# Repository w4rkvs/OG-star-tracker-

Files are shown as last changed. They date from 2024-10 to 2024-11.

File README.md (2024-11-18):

# OG-star-tracker-

Is a fully 3d printed upgradable star tracker that you can make for 60$, I have been working on it for the past two years. It can handle
up to 300mm and 2.5kg. It's also upgradable which means that you can add a another axis which would allow you to use go-to.Don't hesitate to ask me. 
- [List of parts](https://docs.google.com/spreadsheets/d/1kcgIab0JqNLg5WMselIyCQLZJsu3P-vXLvSJgl1yHa8)
- [Assembly video](https://www.youtube.com/watch?v=97YKJrmOWHY)

## Table of Contents
- [Old v1 of the Project](v1/README.md)
- [Mechanics](mechanics/README.md)
- [Firmware](esp32_wireless_control/README.md)

The kit can be purchased for around 150$ on [ogstartech.com](https://www.ogstartech.com/start/). There is a [discord](https://discord.gg/dyFKm79gKJ) for those who are interested or would want to ask me a few questions. New STLs are
on [printables](https://www.printables.com/model/348574-og-star-tracker).

## License

This work is licensed under a
[Creative Commons Attribution-NonCommercial-ShareAlike 4.0 International License](http://creativecommons.org/licenses/by-nc-sa/4.0/)



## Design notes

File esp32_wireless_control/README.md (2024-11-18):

# OG Star Tracker : Wireless Control Hardware (Rev 2.0)

This simple PCB and firmware intends to make it easier to control the OG Star Tracker. If you have any suggestions/ideas about new features or would like to contribute, post in the OG star tracker [discord server](https://discord.com/invite/dyFKm79gKJ) or message me (Discord: jahh#8924).
If you like this work, feel free to connect with me on [Github](https://github.com/jugal2001) or [Linkedin](https://www.linkedin.com/in/jugaljesing/).
### Features:
- Wirelessly Control the tracker from your phone/laptop by connecting to a webpage
- Supports AP (Access Point) and STA (Station) mode
 -- AP  : The ESP32 will create a wifi network which you can connect to
 -- STA : The ESP32 connects to an existing wifi network specified by you, Ex: phone hotspot. (Not fully tested)
- Integrated intervalometer which can control your camera shutter, no need to buy extra hardware. Exposures can be controlled via the webpage
- USB port to power a Dew Heater
- Slewing supported at different speeds.

*If you would like to buy an assembled PCB, contact Ondra Gejdos in the discord server (Creator of the OGST). Alternatively, if you live in India contact me to buy the PCB.*

## Table of Contents
- [PCB](pcb/README.md)
- [Compiling](docs/compiling.md)

## Building guide

One can get the full kit from the the official store at [ogstartech.com](https://ogstartech.com/start) or can build the tracker itself based on the instructions given at [printables](https://www.printables.com/model/348574-og-star-tracker)

## Firmware

The firmware for the PCB is provided in this repository and can be compiled and flashed with the given [instructions](docs/compiling.md).
To control the PCB the tracker will create its own wifi access point with the following default credentials:

```
ssid: OG Star Tracker
password: password123
```

After connection was successful the tracker to actually control it access the ***www.tracker.com** in your browser. The ESP32 provides a webserver for convenient controlling.

## App

If the webserver is not enough there is a app available to improve the accessibility even further.
Check out https://github.com/OndraGejdos/OG-star-tracker-App for more details.

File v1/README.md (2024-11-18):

## Wiring schematics

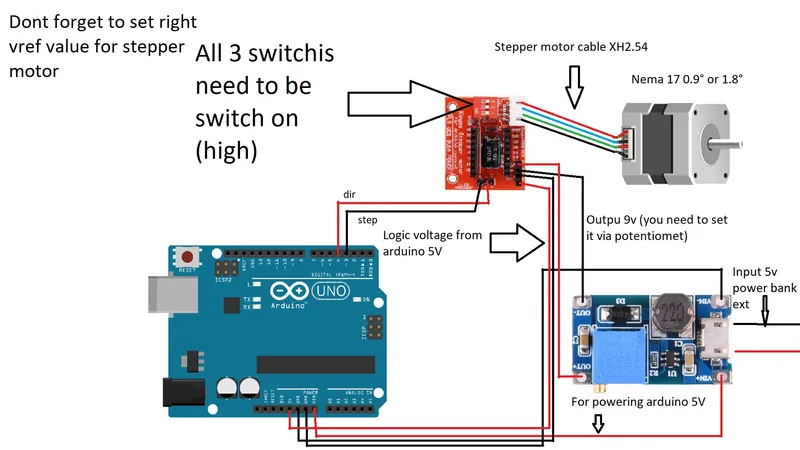
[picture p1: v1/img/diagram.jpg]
schematics


## Choosing parts
You need to main part that is adequate for your latitude. If you live betwen 0°-25° chose : **Main bottom part 0-25 use supports** , 25°-50° use : **Main bottom part 25-50**, 50°-65°+ up use : Main bottom part 45-65.  If you live between 60°-65° you need to use **Main part for laser (14mm) for north 60-65** and **Cover and tightener for north 60-65** because normal parts would not work so north or south.

## Firmware
You need to chose firmware based on your stepper motor. If you have stepper motor which has 400 steps per revolution chose :  firmware simple for Arduino nano 0.9° . If  you have 200 step per rotation stepper motor use : firmware simple for Arduino nano 1.8° . If you want to use different Arduino you might want to change out pins in code.

https://github.com/OndraGejdos/OG-star-tracker-/tree/main/v1/firmware

Or you can use our newly developed pcb to unlock more features. Also you dont need to wire it

https://github.com/OndraGejdos/OG-star-tracker-/tree/main/esp32_wireless_control

### Printing instructions :
Print all parts at 100% infill, except for the following where you can use lower infil:
  ·Large pulley: 50% infill
  ·Ball head holder: 50% infill
  ·Between part: 50% infill
  ·Stationary part: 50% infill
You can use a 0.6mm nozzle for faster printing
Use PLA as the printing material
Parts are oriented in the printing position
Use support only on these specific parts:
  ·Main part: overhang angle 60°
  ·Attachment for slider: overhang angle as specified by your slicer
If you think something is missing, please message me.
Soon, I will upload a bottom main part for those living below 20° latitude.
Clear skies!

3d printed parts chooser : https://docs.google.com/spreadsheets/d/16ynG4nyoBpZOIgJqL5DM0_ZiZSA8s_ifXBTfXa4CrJw/edit?usp=sharing

## Usage guide
You need to first turn it on.

Then you would point laser at polaris.

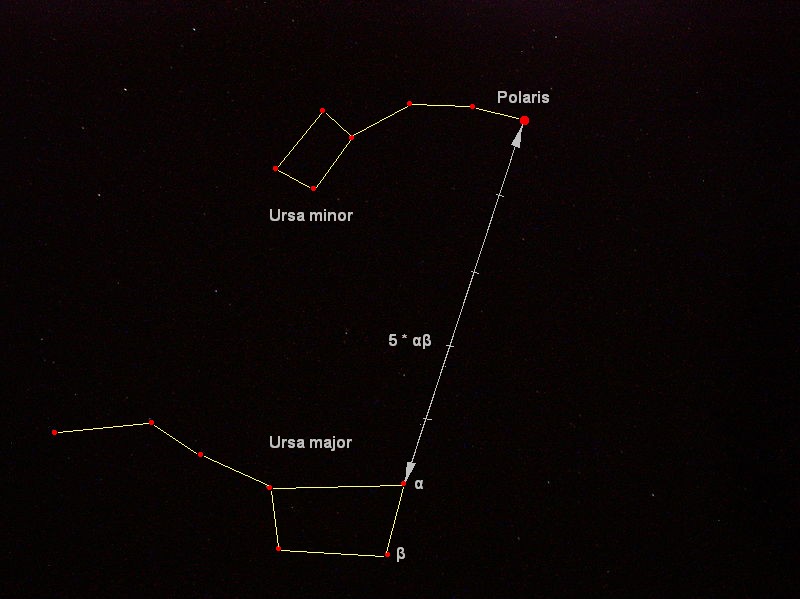
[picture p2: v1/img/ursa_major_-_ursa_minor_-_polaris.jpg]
usage

Then you can point at any celestial object and start shooting.

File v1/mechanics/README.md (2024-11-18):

# Printing Instructions

- OG star tracker mini: Print everything at 100% infill, except large pulley you can use 50% infill.
- For ball head holder, between part and stationary part you can use 50% infill
- For main part, use supports. Support overhang angle is 80°.
- STL files that have "2x" at the end, need to be printed twice.
- If you are confused, look at the 3D model.
- If you don't have M5 threaded inserts, use STLs that have "with thread" in the file name.
- For now, don't print top cover because the software is not ready yet.
- If you don't want to have intervalometer, print top cover without display.
- Software would be hopefully ready in few days.
- Don't forget that this is still beta.
- You can use 0.6mm nozzle.
- Use PLA for printing.
- Parts are oriented in printing position.
- Use supports only on this part: main part, overhang angle 80°
- Print M5 bolt cap twice
- If you think I have missed something, message me.
- Soon I will upload part bottom main part for peoples living below 20°.

Clear skies!

CC BY-NC-SA

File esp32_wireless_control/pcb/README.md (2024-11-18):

Below is list of all parts if you want to assemble it yourself.
### Part list:
| Symbol | Component | Quantity | Example |
|:-: |:-: |:-: |  ---- |
| C1 , C2 , C4  | 100uF 6.3mm Electrolytic Capacitor (THT)| 3 | https://www.sunrom.com/p/100uf-35v-63mm-samwha|
| D1 , D2 | 3mm Red LED THT | 2 | https://evelta.com/3-mm-red-led/ |
| J2 , J3 | 4-pin JST XH2.54mm Socket (90 degree) | 2 | https://www.sunrom.com/p/4-pin-jst-xh-25mm-side-entry-header  |
| J4 | 2.5mm Audio Jack | 1 | https://evelta.com/2-5mm-female-audio-jack-connector-3pin/|
| J5 | USB-A Receptacle | 1 | https://www.sunrom.com/p/usb-a-type-female-pcb-ra-short-body |
| R1 , R2 | 1.2K ohm THT Resistor | 2 | https://evelta.com/1-2k-ohm-resistance-pack-1-4-watt/|
| R3 |  68 ohm THT Resistor  | 1 | ^ |
| U1 | MT3608 Boost converter with USB |  1 |https://www.amazon.in/CENTIoT-MT3608-Adjustable-Module-Boost/dp/B07L6857QN|
| U2 | PC817 Optocoupler | 1 | https://www.sunrom.com/p/pc817-low-voltage-high-density-optocoupler|
| U3 | TMC2209 Stepper Driver| 1 | https://robu.in/product/tmc2209-v3-0-stepper-motor-driver-module/ |
| U5 | ESP32 Devkit V1 (30 pin)|  1 | https://www.electronicscomp.com/esp32-development-board-with-wifi-bluetooth-india|
| - | Female header pins | 2 strips (40x1) | https://www.sunrom.com/p/254mm-40x1-female-straight-header-strip|

### Note:
1. **J1** is a footprint for a 3.5mm audio socket, use this only if you cant find the correct 2.5mm part, or if your camera has a 3.5mm port. [Example](https://robu.in/product/smartelex-audio-jack-3-5mm-trrs-smd/)
2. **U6** is an optional footprint for a 6pin optocoupler in case you cant find a PC817. [MCT2E](https://projectpoint.in/datasheets/pdf/mct2e.pdf). Use only 1 of them.
3. **J5** USB-A Receptacle can be used to power a USB dew heater, dont solder this part if you dont plan to use a dew heater with this board.
4. **C3** is a ceramic cap connected to 3.3V-GND of the ESP32, no need to use this for now.

### Assembly:
- Here is what the fully assembled board is supposed to look like: (Use only 1 TMC2209 for now, only RA axis)

- Use female header pins to mount the TCM2209 drivers and the ESP32 so that they can be replaced easily
- The capacitors underneath the TMC2209 drivers need to be bent by 90-degree and rest on the PCB horizontally as shown:

- Keep the LED at sufficient height so that they can poke through the holes in top surface of the PCB enclosure

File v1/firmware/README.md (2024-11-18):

## Firmware

- step pin: A3
- dir pin: D4

If you want to use it in the south hemisphere, change dir from HIGH to LOW.

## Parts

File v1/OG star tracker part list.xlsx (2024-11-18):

 |  |  |  |  | Og star tracker
Thing you need to buy | price cca per 1ks | quantity | price $ | amazon or aliexpress for reference
625 bearing | 0.15 | 11 | 1.65 | https://www.aliexpress.com/item/32951064437.html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
16008 bearing | 4 | 2 | 8 | https://www.kugellager-express.de/deep-groove-ball-bearing-16008-open-oiled-40x68x9-mm
tmc2209 or 2208 | 7 | 1 | 7 | https://www.aliexpress.com/item/1005002625638207.html?curPageLogUid=98sOKqUEu4fy
gt2 48t pulley | 1 | 2 | 2 | https://www.aliexpress.com/item/1005002875709750.html?curPageLogUid=3kGxXn0tlHgc
gt2 16t pulley | 0.5 | 3 | 1.5 | https://www.aliexpress.com/item/32629617890.html?curPageLogUid=h4Z2GR4t9VFw
belt 122mm | 0.6 | 2 | 1.2 | https://www.aliexpress.com/item/1005004309993673.html?curPageLogUid=W4VxGfOuI1nQ
belt 400mm | 0.75 | 1 | 0.75 | https://www.aliexpress.com/item/1005003250288852.html?curPageLogUid=rBmudUUIxCXB
stepper motor 0,9° | 12 | 1 | 12 | https://www.aliexpress.com/item/1005003475800318.html?curPageLogUid=CAtzuvbHZAjn
you can use 1,8° but it is not so good |  |  | 0
motor driver board the red one | 1 | 1 | 1 | https://www.aliexpress.com/item/32908836265.html?scm_id=1007.13339.291025.0&scm-url=1007.13339.291025.0
arduino uno | 7.5 | 1 | 7.5 | https://www.aliexpress.com/item/32831857729.html?curPageLogUid=D2xkU3JT7git
gt2 idler pulley 20t without teeths bore 3 | 0.6 | 1 | 0.6 | https://www.aliexpress.com/item/32971394035.html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
m5x25 socket head |  | 1 |  |  | buy in your local hardvare store
m5x16 socket head |  | 1 |  |  | buy in your local hardvare store
m3x20 socket head |  | 5 |  |  | buy in your local hardvare store
m5x50 hex head |  | 2 |  |  | buy in your local hardvare store
m3x8 socket head |  | 18 |  |  | buy in your local hardvare store
m3x16 socket head |  | 2 |  |  | buy in your local hardvare store
m3x16 hex head |  | 1 |  |  | buy in your local hardvare store
m3x12 socket head |  | 5 |  |  | buy in your local hardvare store
m3x16 hex head |  | 2 |  |  | buy in your local hardvare store
m5 nut |  | 3 |  |  | buy in your local hardvare store
m3 thread rod 90mm |  | 1 |  |  | buy in your local hardvare store
5mm rod 50mm |  | 2 |  |  | buy in your local hardvare store
m3x6 |  | 18 |  |  | buy in your local hardvare store
m3 threaded inserts |  | 55 | 10 | price for screws and inserts and rods | buy in your local hardvare store
filament pla cca 0,5kg |  | 1 | 10
lcd display with keyes | 2.5 | 1 | 2.5 | https://www.aliexpress.com/item/32842943705.html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
step up |  | 1 | 0.5 | https://www.aliexpress.com/item/1005003112775752.html?curPageLogUid=uhuP8A2T9S2b
cabel for stepper motor (if you dont have) | 0.7 | 1 |  | https://www.aliexpress.com/item/32811275446.html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
 |  | entire price : | 66.2
 |  | price wtihout pla | 55.7 | You make it cheaper if you would buy 1,8° stepper motor no lcd and tmc 2209 in pack of 5 instead of 1 and if you would buy arduino nano. And if you would bought some things second hand . You might be able to do it for ~45 $ if you would try a lot.
optional
threaded insert m5 |  | 3
threaded inseter m3 short |  | 1
parts needed for usage that are not part of assemby
laser pointer get more powerful thean 5mw |  |  | 17 |  |  | lasers are dangerous they can couse serious harm | https://www.amazon.com/Wireless-Demonstrator-Construction-Demonstration-Instruction/dp/B0B94DVX3D
ball head get some that can handle at least 3kg |  |  | 17 |  |  | https://www.aliexpress.com/item/4001227791651.html?curPageLogUid=aTqITsL0oPSzz
good tripod |  |  | ~30 |  |  | buy or get second hand . second hand you might buy surveyors tripods
 |  | with addons | 89.7
Things that you need to own
3d printer
soldering iron (you can do it without)

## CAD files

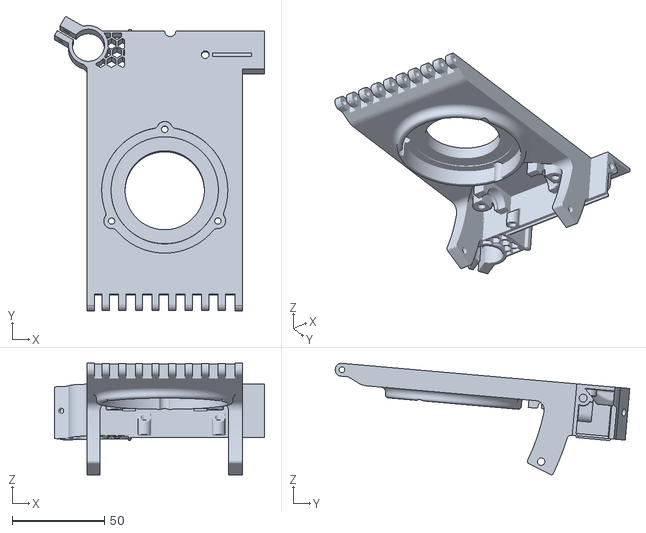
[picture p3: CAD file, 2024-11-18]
mechanics/Main part for different sizes of polar scopes and lasers/Main part for laser or polarscope 17.5mm.stl
113.9 x 159.8 x 60.5

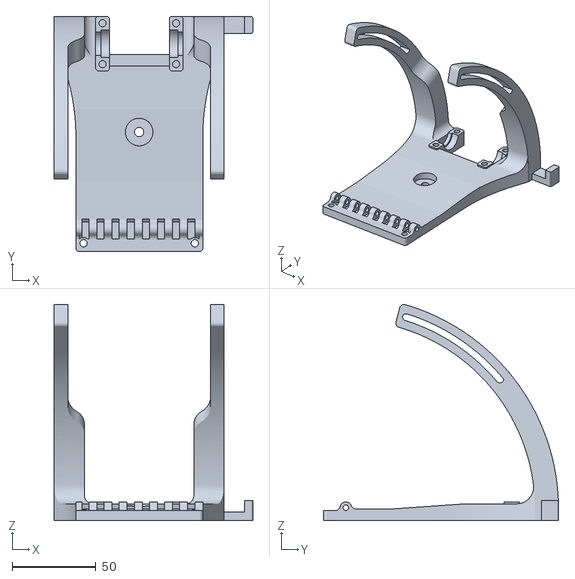
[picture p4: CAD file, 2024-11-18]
mechanics/Bottom assembly/Main bottom part 0-25.stl
118.2 x 139.9 x 128.7

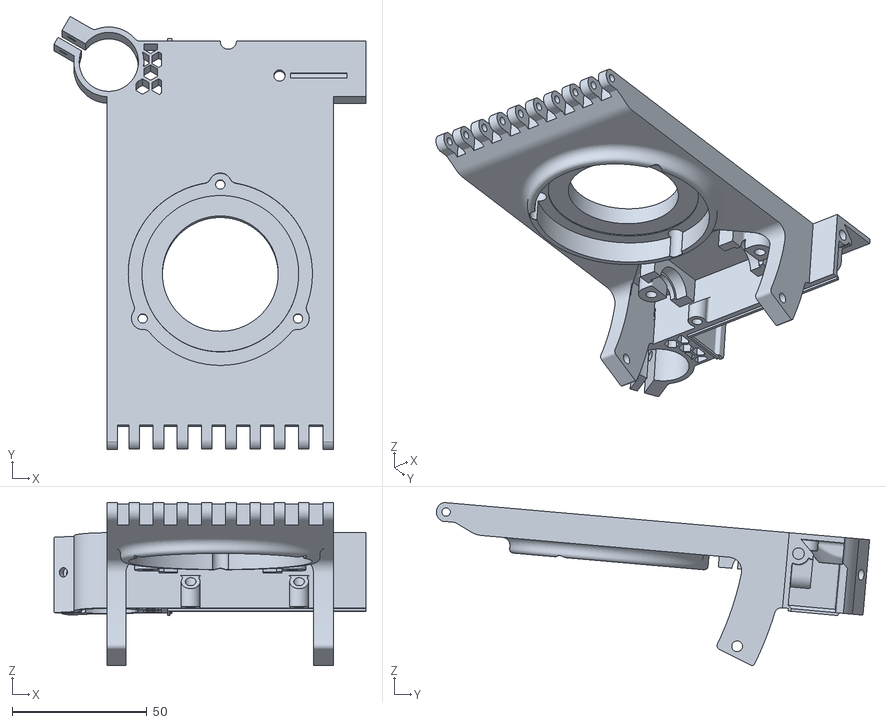
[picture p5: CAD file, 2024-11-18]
mechanics/Main part for different sizes of polar scopes and lasers/Main part for laser or polarscope 22mm.stl
115.9 x 160.9 x 60.5

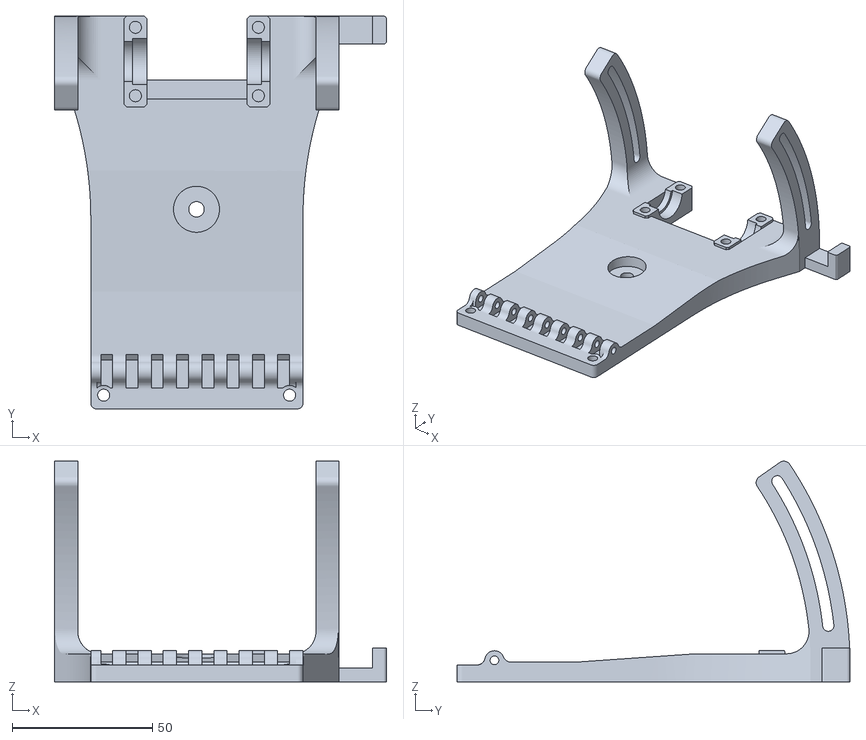
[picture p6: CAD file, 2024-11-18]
mechanics/Bottom assembly/Main bottom part 45 - 65.stl
118.2 x 139.9 x 78.6

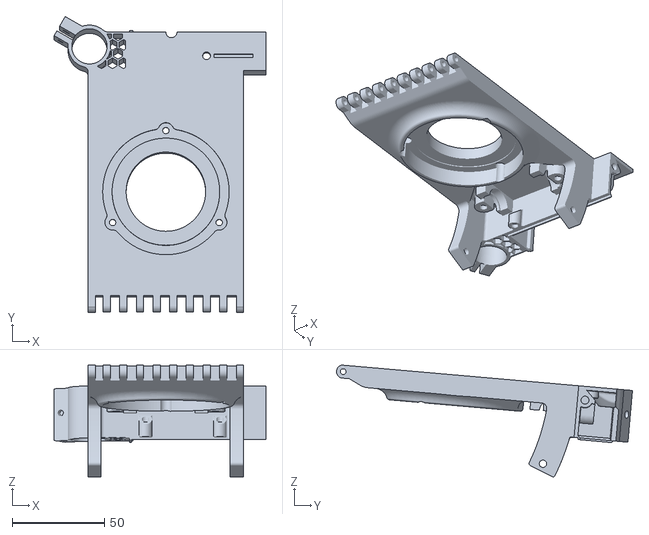
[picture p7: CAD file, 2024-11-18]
mechanics/Main part for different sizes of polar scopes and lasers/Main part for polar scope 19mm.stl
114.6 x 160.2 x 60.5

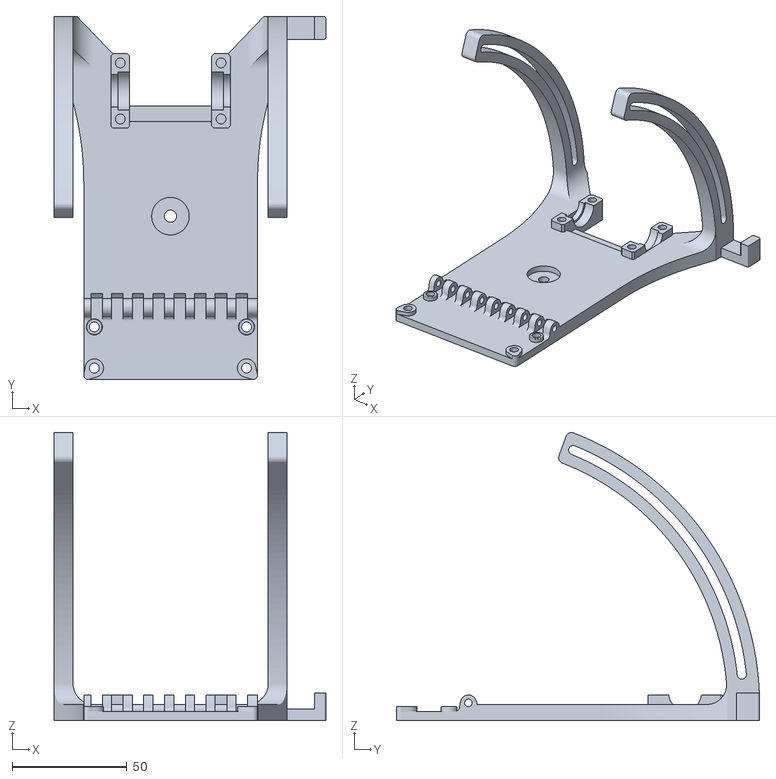
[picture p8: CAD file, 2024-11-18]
v1/mechanics/bottom asembly/bottom main part.stl
118.2 x 157.9 x 125.2

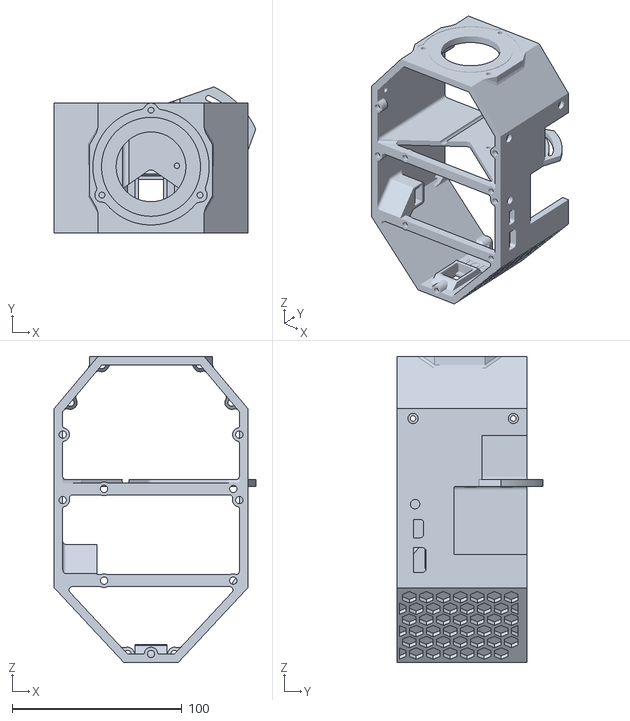
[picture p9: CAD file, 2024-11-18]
mechanics/DEC upgrade RADEK/main-part.stl
118.6 x 86.0 x 180.0

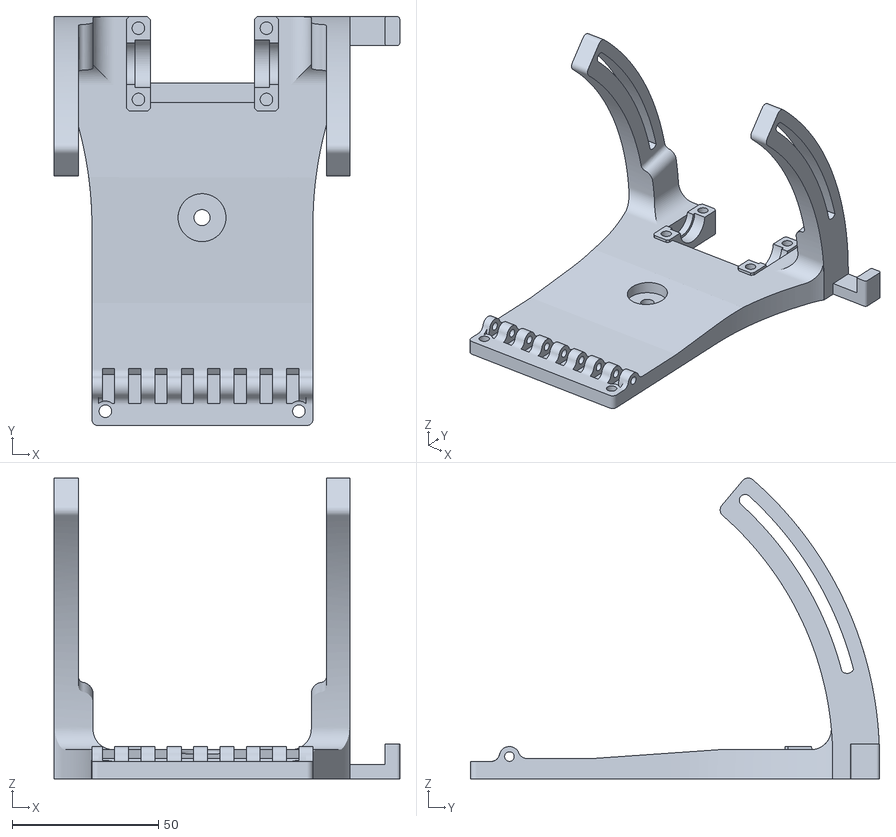
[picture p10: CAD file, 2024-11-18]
mechanics/Bottom assembly/Main bottom part 25-50.stl
118.2 x 139.9 x 102.9

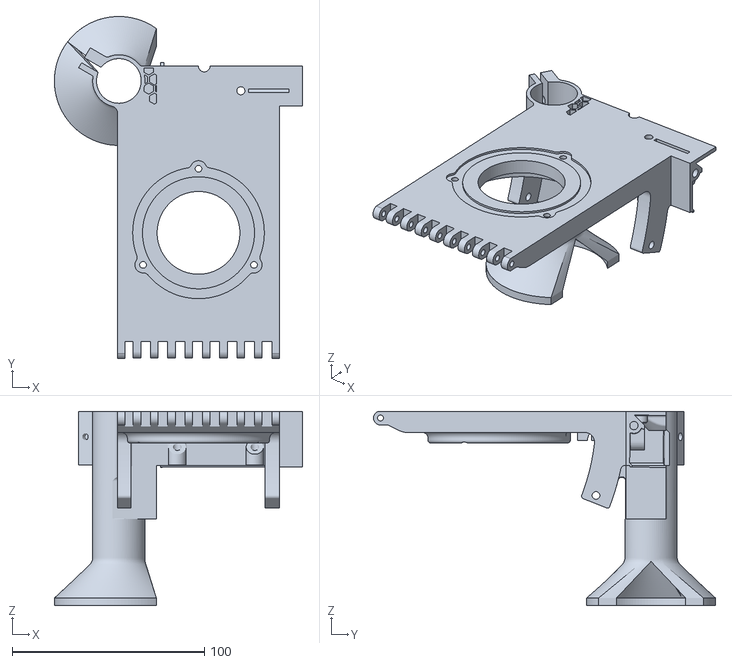
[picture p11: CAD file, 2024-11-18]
mechanics/Main part for different sizes of polar scopes and lasers/Main part for eq3-2 polar scope.stl
129.0 x 177.7 x 101.0

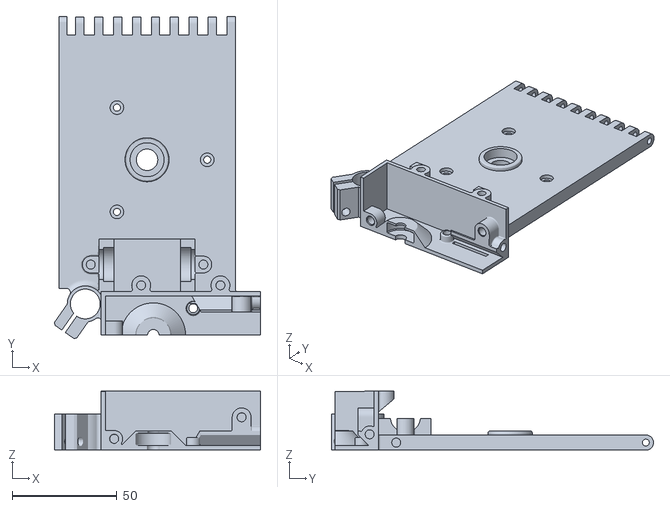
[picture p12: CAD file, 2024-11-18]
v1/mechanics/top asembly/main part.stl
98.2 x 153.5 x 28.0

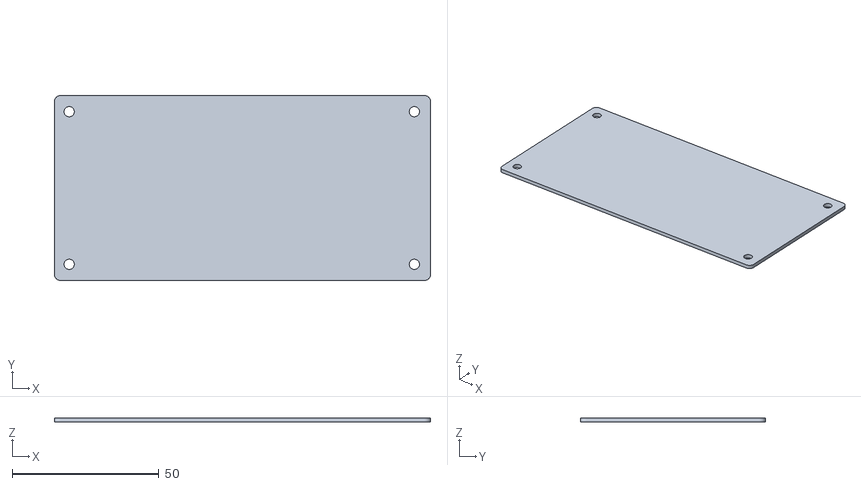
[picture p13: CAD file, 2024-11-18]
mechanics/arduino box/top cover without display.stl
128.1 x 63.0 x 1.50

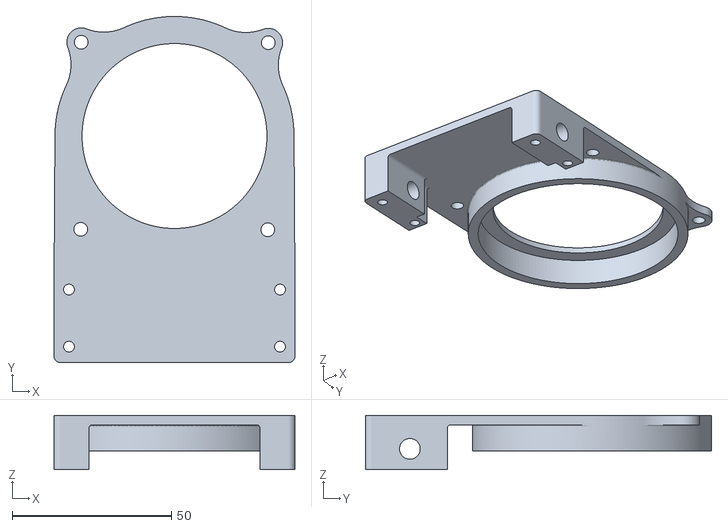
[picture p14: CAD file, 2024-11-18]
mechanics/Bottom assembly/Middle holder of bearing with m5 threaded insert.stl
75.6 x 108.6 x 17.1

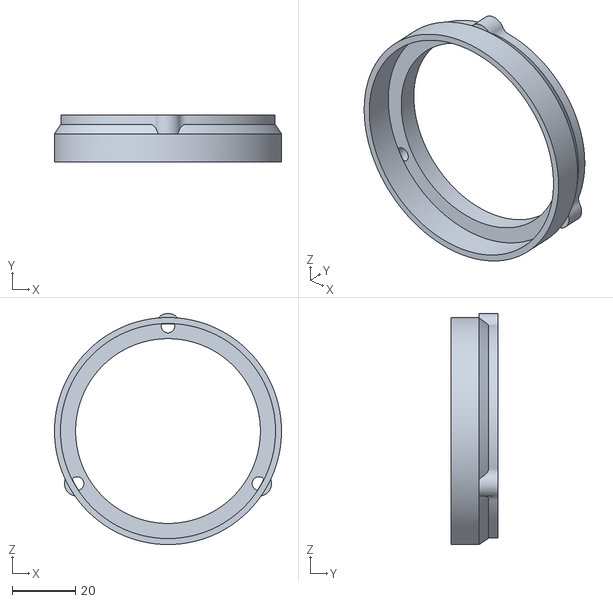
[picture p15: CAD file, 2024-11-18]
mechanics/DEC upgrade RADEK/middle-bearing-holder.stl
72.0 x 15.0 x 73.3

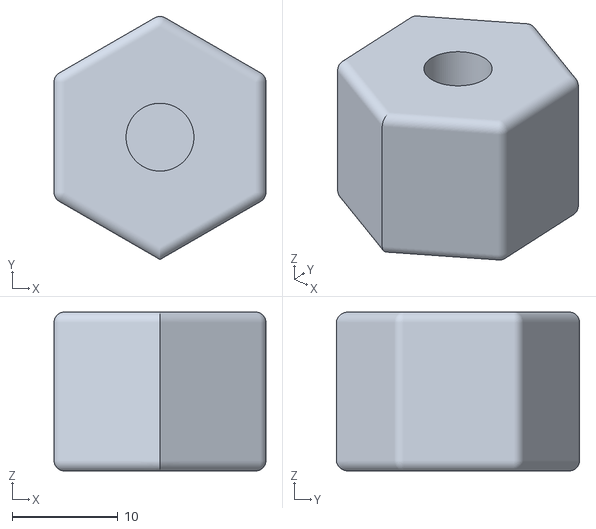
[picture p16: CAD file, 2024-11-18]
mechanics/Knobs and rest of the things/rotator with m5 threaded insert.stl
20.0 x 22.9 x 15.0

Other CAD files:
mechanics/Main part for different sizes of polar scopes and lasers/Main part for laser 14mm.stl
mechanics/Main part for different sizes of polar scopes and lasers/Main part for laser or polarscope 23mm.stl
mechanics/Main part for different sizes of polar scopes and lasers/Main part for laser (14mm) for north 60-65.stl
mechanics/Pcb box/Bottom part of the box.stl
mechanics/Bottom assembly/Stationary part all threads are 3d printed.stl
mechanics/Bottom assembly/Stationary part for surveyors tripod with m5 threaded insert.stl
mechanics/Bottom assembly/Stationary part with m5 threaded inser and 3 8 threaded insert.stl
mechanics/Bottom assembly/Stationary part with m5 threaded inser and 3d printed 1 4 thread.stl
mechanics/Bottom assembly/stationary-part-3-8-thread-m5-insert.stl
mechanics/DEC upgrade RADEK/DEC_Arca_clamp_moving.stl
mechanics/DEC upgrade RADEK/DEC_Arca_clamp_static.stl
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

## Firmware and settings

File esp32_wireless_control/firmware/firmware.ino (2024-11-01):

#include <WiFi.h>
#include <WebServer.h>
#include <DNSServer.h>
#include <string.h>
#include <esp_wifi.h>
#include <EEPROM.h>
#include "config.h"
#include "strings.h"

// try to update every time there is breaking change
const int firmware_version = 6;

// Set your Wi-Fi credentials
const byte DNS_PORT = 53;
const char* ssid = "OG Star Tracker";  //change to your SSID
const char* password = "password123";  //change to your password, must be 8+ characters
//If you are using AP mode, you can access the website using the below URL
const String website_name = "www.tracker.com";
const int dither_intensity = 5;
#define MIN_CUSTOM_SLEW_RATE 2

//Time b/w two rising edges should be 133.3333 ms
//66.666x2  ms
//sidereal rate = 0.00416 deg/s
//for 80Mhz APB (TIMER frequency)
#ifdef STEPPER_0_9
enum tracking_rate_state { TRACKING_SIDEREAL = 2659383,  //SIDEREAL (23h,56 min)
                           TRACKING_SOLAR = 2666666,     //SOLAR (24h)
                           TRACKING_LUNAR = 2723867 };   //LUNAR (24h, 31 min)
const int arcsec_per_step = 2;
#else  //stepper 1.8 deg
enum tracking_rate_state { TRACKING_SIDEREAL = 5318765,  //SIDEREAL (23h,56 min)
                           TRACKING_SOLAR = 5333333,     //SOLAR (24h)
                           TRACKING_LUNAR = 5447735 };   //LUNAR (24h, 31 min)
const int arcsec_per_step = 4;
#endif

volatile enum tracking_rate_state tracking_rate = TRACKING_SIDEREAL;  //default to sidereal rate

int slew_speed = 0, exposure_count = 0, exposure_duration = 0, dither_enabled = 0, focal_length = 0, pixel_size = 0, steps_per_10pixels = 0, direction = c_DIRECTION;
float arcsec_per_pixel = 0.0;
unsigned long blink_millis = 0;
uint64_t exposure_delay = 0;

//state variables
bool s_slew_active = false, s_tracking_active = true, s_capturing = false;  //change s_tracking_active state to false if you want tracker to be OFF on power-up
bool disable_tracking = false;
int exposures_taken = 0;
enum photo_control_state { ACTIVE,
                           DELAY,
                           DITHER,
                           INACTIVE };
volatile enum photo_control_state photo_control_status = INACTIVE;

float direction_left_bias = 0.5, direction_right_bias = 0.5;
int previous_direction = -1;

//2 bytes occupied by each int
//eeprom addresses
#define DITHER_ADDR 1
#define FOCAL_LEN_ADDR 3
#define PIXEL_SIZE_ADDR 5
#define DITHER_PIXELS 30  //how many pixels to dither

WebServer server(80);
DNSServer dnsServer;
hw_timer_t* timer_tracking = NULL;     //for tracking and slewing rate
hw_timer_t* timer_interval = NULL;     //for intervalometer control
hw_timer_t* timer_web_timeout = NULL;  //for webclient timeout control

void IRAM_ATTR timer_web_timeout_ISR() {
  handleSlewOff();
}

void IRAM_ATTR timer_tracking_ISR() {
  //tracking ISR
  digitalWrite(AXIS1_STEP, !digitalRead(AXIS1_STEP));  //toggle step pin at required frequency
}

void IRAM_ATTR timer_interval_ISR() {
  Serial.println("----");
  //intervalometer ISR
  switch (photo_control_status) {
    case ACTIVE:
      exposures_taken++;
      Serial.println("exposures_taken = " + String(exposures_taken) + "/" + String(exposure_count));
      if (exposure_count == exposures_taken) {
        Serial.println("State: Stopping intervalometer");
        // no more images to capture, stop
        disableIntervalometer();
        exposure_count = 0;
        s_capturing = false;
        photo_control_status = INACTIVE;

        if (disable_tracking) {
          s_tracking_active = false;
          timerAlarmDisable(timer_tracking);
        }
      } else if (exposures_taken % 3 == 0 && dither_enabled) {
        Serial.println("State: Dithering");
        // user has active dithering and this is %3 image, stop capturing and run dither routine
        photo_control_status = DITHER;
        stopCapture();
        timerStop(timer_interval);  //pause the timer, wait for dither to finish in main loop
      } else {
        Serial.println("State: Wait for next shot");
        // run normally
        timerWrite(timer_interval, exposure_delay);
        stopCapture();
        photo_control_status = DELAY;
      }
      break;
    case DELAY:
      Serial.println("State: Taking shot");
      timerWrite(timer_interval, 0);
      startCapture();
      photo_control_status = ACTIVE;
      break;
  }
}

// Handle requests to the root URL ("/")
void handleRoot() {
  String formattedHtmlPage = String(html);
  formattedHtmlPage.replace("%north%", (direction ? "selected" : ""));
  formattedHtmlPage.replace("%south%", (!direction ? "selected" : ""));
  formattedHtmlPage.replace("%dither%", (dither_enabled ? "checked" : ""));
  formattedHtmlPage.replace("%focallen%", String(focal_length).c_str());
  formattedHtmlPage.replace("%pixsize%", String((float)pixel_size / 100, 2).c_str());
  server.send(200, MIME_TYPE_HTML, formattedHtmlPage);
}

void handleOn() {
  int tracking_speed = server.arg(TRACKING_SPEED).toInt();
  switch (tracking_speed) {
    case 0:  //sidereal rate
      tracking_rate = TRACKING_SIDEREAL;
      break;
    case 1:  //solar rate
      tracking_rate = TRACKING_SOLAR;
      break;
    case 2:  //lunar rate
      tracking_rate = TRACKING_LUNAR;
      break;
    default:
      tracking_rate = TRACKING_SIDEREAL;
      break;
  }
  direction = server.arg(DIRECTION).toInt();
  s_tracking_active = true;
  initTracking();
}

void handleOff() {
  s_tracking_active = false;
  timerAlarmDisable(timer_tracking);
  server.send(200, MIME_TYPE_TEXT, TRACKING_OFF);
}

void handleLeft() {
  if (!s_slew_active) {  //if slew is not active - needed for ipad (passes multiple touchon events)
    slew_speed = server.arg(SPEED).toInt();
    //limit custom slew speed to 2-400
    slew_speed = slew_speed > MAX_CUSTOM_SLEW_RATE ? MAX_CUSTOM_SLEW_RATE : slew_speed < MIN_CUSTOM_SLEW_RATE ? MIN_CUSTOM_SLEW_RATE
                                                                                                              : slew_speed;
    initSlew(0);
  }
}

void handleRight() {
  if (!s_slew_active) {  //if slew is not active - needed for ipad (passes multiple touchon events)
    slew_speed = server.arg(SPEED).toInt();
    //limit custom slew speed to 2-400
    slew_speed = slew_speed > MAX_CUSTOM_SLEW_RATE ? MAX_CUSTOM_SLEW_RATE : slew_speed < MIN_CUSTOM_SLEW_RATE ? MIN_CUSTOM_SLEW_RATE
                                                                                                              : slew_speed;
    initSlew(1);  //reverse direction
  }
}

void handleSlewOff() {
  if (s_slew_active) {  //if slew is active needed for ipad (passes multiple touchoff events)
    s_slew_active = false;
    timerAlarmDisable(timer_web_timeout);
    timerDetachInterrupt(timer_web_timeout);
    timerEnd(timer_web_timeout);
    timerAlarmDisable(timer_tracking);
    initTracking();
  }
}

void handleStartCapture() {
  if (photo_control_status == INACTIVE) {
    exposure_duration = server.arg(EXPOSURE).toInt();
    exposure_count = server.arg(NUM_EXPOSURES).toInt();
    dither_enabled = server.arg(DITHER_ENABLED).toInt();
    focal_length = server.arg(FOCAL_LENGTH).toInt();
    pixel_size = server.arg(PIXEL_SIZE).toInt();
    disable_tracking = server.arg(DISABLE_TRACKING_ON_FINISH).toInt();

    exposures_taken = 0;

    if ((exposure_duration == 0 || exposure_count == 0)) {
      server.send(200, MIME_TYPE_TEXT, INVALID_EXPOSURE_VALUES);
      return;
    }

    if (dither_enabled && (focal_length == 0 || pixel_size == 0)) {
      server.send(200, MIME_TYPE_TEXT, INVALID_DITHER_VALUES);
      return;
    }

    updateEEPROM(dither_enabled, focal_length, pixel_size);
    arcsec_per_pixel = (((float)pixel_size / 100.0) / focal_length) * 206.265;        //div pixel size by 100 since we multiplied it by 100 in html page
    steps_per_10pixels = (int)(((arcsec_per_pixel * 10.0) / arcsec_per_step) + 0.5);  //add 0.5 to round up float to nearest int while casting
    Serial.println("steps per 10px: ");
    Serial.println(steps_per_10pixels);

    s_capturing = true;
    photo_control_status = ACTIVE;
    exposure_delay = ((exposure_duration - 3) * 2000);  // 3 sec delay
    initIntervalometer();
    server.send(200, MIME_TYPE_TEXT, CAPTURE_ON);
  } else {
    server.send(200, MIME_TYPE_TEXT, CAPTURE_ALREADY_ON);
  }
}

void handleAbortCapture() {
  if (photo_control_status == INACTIVE) {
    server.send(200, MIME_TYPE_TEXT, CAPTURE_ALREADY_OFF);
    return;
  }

  disableIntervalometer();
  exposure_count = 0;
  exposure_duration = 0;
  photo_control_status = INACTIVE;
  server.send(200, MIME_TYPE_TEXT, CAPTURE_OFF);
  s_capturing = false;
}

void handleStatusRequest() {
  if (s_slew_active) {
    timerWrite(timer_web_timeout, 0);  //reset timer while slew on, prove still connected to web/app
    server.send(200, MIME_TYPE_TEXT, SLEWING);
  }
  if (photo_control_status != INACTIVE) {
    char status[60];
    sprintf(status, CAPTURES_REMAINING, exposure_count - exposures_taken);
    server.send(200, MIME_TYPE_TEXT, status);
    return;
  }

  if (!s_tracking_active && photo_control_status == INACTIVE) {
    server.send(200, MIME_TYPE_TEXT, IDLE);
    return;
  }

  if (s_tracking_active) {
    server.send(200, MIME_TYPE_TEXT, TRACKING_ON);
    return;
  }

  server.send(204, MIME_TYPE_TEXT, "dummy");

  // TODO add detection for capturing
}

void handleVersion() {
  server.send(200, MIME_TYPE_TEXT, (String)firmware_version);
}

void writeEEPROM(int address, int value) {
  byte high = value >> 8;
  byte low = value & 0xFF;
  EEPROM.write(address, high);
  EEPROM.write(address + 1, low);
}

int readEEPROM(int address) {
  byte high = EEPROM.read(address);
  byte low = EEPROM.read(address + 1);
  return ((high << 8) + low);
}

void updateEEPROM(int dither, int focal_len, int pix_size) {
  if (readEEPROM(DITHER_ADDR) != dither) {
    writeEEPROM(DITHER_ADDR, dither);
    //Serial.println("dither updated");
  }
  if (readEEPROM(FOCAL_LEN_ADDR) != focal_len) {
    writeEEPROM(FOCAL_LEN_ADDR, focal_len);
    //Serial.println("focal length updated");
  }
  if (readEEPROM(PIXEL_SIZE_ADDR) != pix_size) {
    writeEEPROM(PIXEL_SIZE_ADDR, pix_size);
    //Serial.println("pix size updated");
  }
  EEPROM.commit();
}

void setMicrostep(int microstep) {
  switch (microstep) {
    case 8:
      digitalWrite(MS1, LOW);
      digitalWrite(MS2, LOW);
      break;
    case 16:
      digitalWrite(MS1, HIGH);
      digitalWrite(MS2, HIGH);
      break;
    case 32:
      digitalWrite(MS1, HIGH);
      digitalWrite(MS2, LOW);
      break;
    case 64:
      digitalWrite(MS1, LOW);
      digitalWrite(MS2, HIGH);
      break;
  }
}

void initSlew(int dir) {
  s_slew_active = true;
  timer_web_timeout = timerBegin(2, 40000, true);
  timerAttachInterrupt(timer_web_timeout, &timer_web_timeout_ISR, true);
  timerAlarmWrite(timer_web_timeout, 12000, true);  //12000 = 6 secs timeout, send status 5 sec poll (reset on poll)
  timerAlarmEnable(timer_web_timeout);
  server.send(200, MIME_TYPE_TEXT, SLEWING);
  digitalWrite(AXIS1_DIR, dir);  //set slew direction
  timerAlarmDisable(timer_tracking);
  setMicrostep(8);
  timerAlarmWrite(timer_tracking, (2 * tracking_rate) / slew_speed, true);  //2*tracking rate (16 mstep vs 8) / slew_speed = multiple of tracking rate
  timerAlarmEnable(timer_tracking);
}

void initTracking() {
  digitalWrite(AXIS1_DIR, direction);
  setMicrostep(16);
  timerAlarmWrite(timer_tracking, tracking_rate, true);
  if (s_tracking_active) {
    timerAlarmEnable(timer_tracking);
    server.send(200, MIME_TYPE_TEXT, TRACKING_ON);
  } else {
    timerAlarmDisable(timer_tracking);
    server.send(200, MIME_TYPE_TEXT, TRACKING_OFF);
  }
}

void initIntervalometer() {
  timer_interval = timerBegin(1, 40000, true);
  timerAttachInterrupt(timer_interval, &timer_interval_ISR, true);
  timerAlarmWrite(timer_interval, (exposure_duration * 2000), true);  //2000 because prescaler cant be more than 16bit, = 1sec ISR freq
  timerAlarmEnable(timer_interval);
  startCapture();
}

void disableIntervalometer() {
  stopCapture();
  timerAlarmDisable(timer_interval);
  timerDetachInterrupt(timer_interval);
  timerEnd(timer_interval);
}

void stopCapture() {
  digitalWrite(INTERV_PIN, LOW);
}

void startCapture() {
  digitalWrite(INTERV_PIN, HIGH);
}

void ditherRoutine() {
  int i = 0, j = 0;
  timerAlarmDisable(timer_tracking);
  int random_direction = biased_random_direction(previous_direction);
  previous_direction = random_direction;
  digitalWrite(AXIS1_DIR, random_direction);  //dither in a random direction
  delay(500);

  for (i = 0; i < dither_intensity; i++) {
    for (j = 0; j < steps_per_10pixels; j++) {
      digitalWrite(AXIS1_STEP, !digitalRead(AXIS1_STEP));
      delay(10);
      digitalWrite(AXIS1_STEP, !digitalRead(AXIS1_STEP));
      delay(10);
    }
  }

  delay(1000);
  initTracking();
  delay(3000);  //settling time after dither
}

void setup() {
  Serial.begin(115200);
  EEPROM.begin(512);  //SIZE = 6 bytes, 2 bytes for each variable
  //fetch values from EEPROM
  dither_enabled = readEEPROM(DITHER_ADDR);
  focal_length = readEEPROM(FOCAL_LEN_ADDR);
  pixel_size = readEEPROM(PIXEL_SIZE_ADDR);

#ifdef AP
  WiFi.mode(WIFI_MODE_AP);
  WiFi.softAP(ssid, password);
  delay(500);
  Serial.println("Creating Wifi Network");

  //ANDROID 10 WORKAROUND==================================================
  //set new WiFi configurations
  WiFi.disconnect();
  Serial.println("reconfig WiFi...");
  /*Stop wifi to change config parameters*/
  esp_wifi_stop();
  esp_wifi_deinit();
  /*Disabling AMPDU RX is necessary for Android 10 support*/
  wifi_init_config_t my_config = WIFI_INIT_CONFIG_DEFAULT();  //We use the default config ...
  my_config.ampdu_rx_enable = 0;                              //... and modify only what we want.
  Serial.println("WiFi: Disabled AMPDU...");
  esp_wifi_init(&my_config);  //set the new config = "Disable AMPDU"
  esp_wifi_start();           //Restart WiFi
  delay(500);
  //ANDROID 10 WORKAROUND==================================================
#else
  WiFi.mode(WIFI_MODE_STA);  // Set ESP32 in station mode
  WiFi.begin(ssid, password);
  Serial.println("Connecting to Network in STA mode");
  while (WiFi.status() != WL_CONNECTED) {
    delay(1000);
    Serial.print(".");
  }
#endif
  dnsServer.setTTL(300);
  dnsServer.setErrorReplyCode(DNSReplyCode::ServerFailure);
  dnsServer.start(DNS_PORT, website_name, WiFi.softAPIP());

  server.on("/", HTTP_GET, handleRoot);
  server.on("/on", HTTP_GET, handleOn);
  server.on("/off", HTTP_GET, handleOff);
  server.on("/left", HTTP_GET, handleLeft);
  server.on("/right", HTTP_GET, handleRight);
  server.on("/stopslew", HTTP_GET, handleSlewOff);
  server.on("/start", HTTP_GET, handleStartCapture);
  server.on("/abort", HTTP_GET, handleAbortCapture);
  server.on("/status", HTTP_GET, handleStatusRequest);
  server.on("/version", HTTP_GET, handleVersion);

  // Start the server
  server.begin();

#ifdef AP
  Serial.println(WiFi.softAPIP());
#else
  Serial.println(WiFi.localIP());
#endif
  pinMode(INTERV_PIN, OUTPUT);
  pinMode(STATUS_LED, OUTPUT);
  pinMode(AXIS1_STEP, OUTPUT);
  pinMode(AXIS1_DIR, OUTPUT);
  pinMode(EN12_n, OUTPUT);
  pinMode(MS1, OUTPUT);
  pinMode(MS2, OUTPUT);
  digitalWrite(AXIS1_STEP, LOW);
  digitalWrite(EN12_n, LOW);

  timer_tracking = timerBegin(0, 2, true);
  timerAttachInterrupt(timer_tracking, &timer_tracking_ISR, true);
  initTracking();
}

void loop() {
  if (s_slew_active) {
    //blink status led if mount is in slew mode
    if (millis() - blink_millis >= 150) {
      digitalWrite(STATUS_LED, !digitalRead(STATUS_LED));
      blink_millis = millis();
    }
  } else {
    //turn on status led if sidereal tracking is ON
    digitalWrite(STATUS_LED, (s_tracking_active == true));
  }

  if (photo_control_status == DITHER) {
    disableIntervalometer();
    ditherRoutine();
    photo_control_status = ACTIVE;
    initIntervalometer();
  }
  server.handleClient();
  dnsServer.processNextRequest();
}

// when tracker moves left, next time its 5% higher chance tracked will move right
// with this tracker should keep in the middle in average
int biased_random_direction(int previous_direction) {
  // Adjust probabilities based on previous selection
  if (previous_direction == 0) {
    direction_left_bias = 0.45;   // Lower probability for 0
    direction_right_bias = 0.55;  // Higher probability for 1
  }
  if (previous_direction == 1) {
    direction_left_bias = 0.55;   // Higher probability for 0
    direction_right_bias = 0.45;  // Lower probability for 1
  }

  float rand_val = random(100) / 100.0;  // random number between 0.00 and 0.99

  if (rand_val < direction_left_bias) {
    return 0;
  } else {
    return 1;
  }
}

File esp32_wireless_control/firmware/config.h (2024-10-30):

#ifndef CONFIG
#define CONFIG

/*****USER DEFINED*****/
//AP mode by default: ESP32 will create a wifi network which you can connect to
#define AP              //comment this line if you want ESP32 to connect to your existing wifi network/hotspot
#define c_DIRECTION 1   //1 is for north hemisphere and 0 for south hemisphere
#define MAX_CUSTOM_SLEW_RATE 400
#define STEPPER_0_9     //uncomment this line if you have a 0.9 degree NEMA17
//#define STEPPER_1_8   //uncomment this line if you have a 1.8 degree NEMA17, and comment the above line
/**********************/



/*****DO NOT MODIFY BELOW*****/
//LEDs for intervalometer status and general purpose status led
#define INTERV_PIN    25
#define STATUS_LED    26

//Stepper driver pins -- intended for TMC2209 for now
//AXIS 1 - RA
#define AXIS1_STEP     5 
#define AXIS1_DIR     15
#define SPREAD_1       4
//AXIS 2 - DEC
#define AXIS2_STEP    19
#define AXIS2_DIR     18
#define SPREAD_2      21
//common pins
#define MS1           23
#define MS2           22
#define EN12_n        17

#endif

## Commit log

2024-10-27 -Renamed tspeed to trackingSpeed in html -Renamed TSPEED to TRACKING_SPEED -Refomated line 35 in firmware.ino -Remove white space in firmware.ino -changed slew direction button icons to <(&lt;) and >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
2024-10-29 Update firmware.ino
    Slew rates now a multiple of tracking rate - inline with most astromony software Web interface updated to allow custom slew rate (instead of from config file) - inline with common astro software Hold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
2024-10-29 Update strings.cpp
    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
2024-10-29 Update strings.h
    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
2024-10-29 Update config.h
    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
2024-10-29 changed comment for tracking timer changed left and right separator for slew buttons
2024-10-30 Added onmouseLeave for pc browser to end slew if mouse moves out of button while pressed Added ontouchcancel for touchscreens if touch is interrupted slew is ended Added slew Abort button for all oth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
    [firmware.ino]
2024-10-30 add max 400 to website add reset to 400 for anyvalue that is above 400 in handle left and right
    [firmware.ino]
2024-11-01 Bug fix for non-functioning dithering
    [firmware.ino]
2024-11-17 firmware: add platformio compilation support
    This adds support to build the firmware for the esp32 devkit with
    platformio.
    It may not be clean but until classes are introduced this is the
    way to go.
2024-11-17 moved old Firmware -> v1/firmware
    Moved the old and experimental firmware files to the v1 folder
    to indicate to prevent confusions.
    [arduino uno !TEST!.ino, firmware simple for arduino nano and 0.9° stepper .ino.ino, firmware simple for arduino nano and 1,8°.ino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]
2024-11-17 moved old stls -> v1/mechanics
    [attachment for slider.stl, ball head holder.stl, between part.stl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]
2024-11-17 moved v1 part list to v1 folder
    [OG star tracker part list.xlsx]
2024-11-17 mechanics: add most recent stl files from printables
    [1 part of gearboox.stl, 2 part of gearbox.stl, 3 part of gearbox.stl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]
2024-11-17 esp32: move pcb files -> pcb
2024-11-17 esp32: docs: add compiling guide for platformio
2024-11-17 esp32: document how to get started with v2
